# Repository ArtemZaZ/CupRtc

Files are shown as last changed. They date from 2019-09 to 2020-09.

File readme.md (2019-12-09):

# Проект для кубка РТК
 Case_of_Cup содержит модель подарочного кубка в среде SolidWorks.
Пожелания, жалобы, конструктивная критика и тому подобное принимается в [вк](https://vk.com/al_kom_ru).

Фото9

Описание, как залить новую информацию для кубка описано в документе "Прошивка кубка.docx"

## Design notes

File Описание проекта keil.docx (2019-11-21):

# Структура проекта в keil

Данный проект задействует следующую периферию процессора stm32f103C8T6:

- DMA1 и TIM3 для работы с адресными светодиодами;
- TIM4 для реализации функций задержек;
- PA10,PA11,PA12,PA15,PB3,PB4 для работы с LCD дисплеем;
- SPI2 для работы с динамиком и внешней памятью EEPROM, PA9 и PB12 как CS соответственно;
- PA1 для тактовой кнопки;
- UART2 – для общения с ПК.

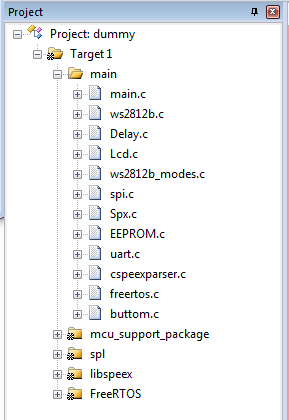
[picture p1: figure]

Данный проект задействует пакет библиотек SPL, LibSpeex и FreeRTOS. Важно замtтить, что большая часть функций переписана для успешной работы с операционной системой FreeRTOS. Также реализованы следующие библиотеки:

- ws2812b – работа с адресными светодиодами;
- Delay – функции задержек за счет таймера;
- Lcd – работа с lcd-дисплеем;
- ws2812b-modes – различные режимы работы светодиодов;
- spi – настройка интерфейса и таймера для работы динамика;
- Spx – инициализации библиотек libspeex и функций по запуску аудиофайла;
- EEPROM – для работы с внешней энергонезависимой памятью;
- uart – для записи данных с ПК на плату;
- cspeexparcer – для расшифровки пакета данных полученных по uart-у;
- freertos – настройка работы диспетчера задач и функций для него;
- buttom – функции для работы с тактовой кнопкой.

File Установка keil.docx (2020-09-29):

Итак, для прошивки кубка нам понадобиться µVision IDE – Keil. Качнуть можно его с многих ресурсов, труда не составит. Но есть прякол. В кейле который вы скачаете скорее всего будет мало место в линковщике (сколько не помню, но прошивка не соберется точно). Для решения проблемы надо стать немножко пиратом.

Далее говорить нечего, просто оставляю две ссылки на видосики, которые помогут спокойно решить проблему (ссылки на необходимые файлы можно найти в описании к видео).

(http://www2.keil.com/mdk5/uvision/)https://www.youtube.com/watch?v=bSmml5kYX14

https://www.youtube.com/watch?v=xSqIlKJOs6A

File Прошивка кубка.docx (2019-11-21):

# Прошивка кубка

## Подготовка файлов для отправки в кубок

Перед тем как начать заливать информацию в кубок по uart-у, необходимо убедиться, что на компьютере установлен Python3. Версия питона ниже не подойдет. Далее качаем архив с проектом с GitHub, вот ссыль

https://github.com/RTC-SCTB/CupRtc

Если качали из мастер-ветки, то в корне есть две директории: keil и Python. Нас интересует второе. В директории Python нас могут заинтересовать два файла: audio.wav и conf.json.

conf.json

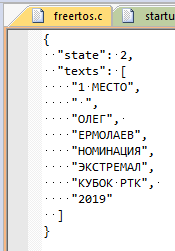
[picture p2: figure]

Открываем. Я открыл его в своем случае в keil-е. Советую открывать в каком-нибудь редакторе кода, т.к. можно будет указать кодировку файла, а она должна быть utf-8 (в кейле параметр encode in utf-8 without signature). В этом файле мы прописываем 8 текстов для дисплея и указываем место. Параметр state в данной конфигурации не учувствует, его можно не менять. Тексты записывать нужно из расчета на то, что в строку дисплея поместится 16 символов, могут быть написаны как в кириллице, так и в латинице. Тексты выводятся попарно, в первой и второй строке соответственно (1 и 2, 3 и 4 и т.д.). Заполняем примерно, как показано на скрине.

audio.wav

Это наш файл аудио, которое будет транслироваться на динамик.

Для начала нужно установить speex-кодировщик. Откуда я качал, не помню, поэтому в корне проекта лежит архив SpeexACM_1.0.1.1.zip. Его открываем, и запускаем exe-шник. (Маленькая пометка – делалось все на винде, как на линуксе будет, не известно).

После этого нам нужен какой-нибудь аудио-редактор, я использую jetAudio, он бесплатный, вот ссыль http://www.jetaudio.com/download/. Устанавливаем. Открываем, и переходим в окно конвертации.

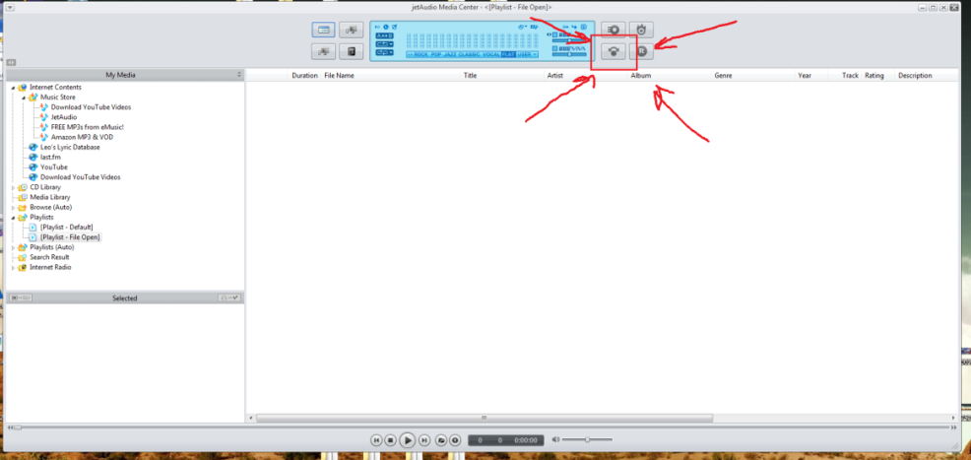
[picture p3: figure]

После этого добавляем новый файл в конвертер:

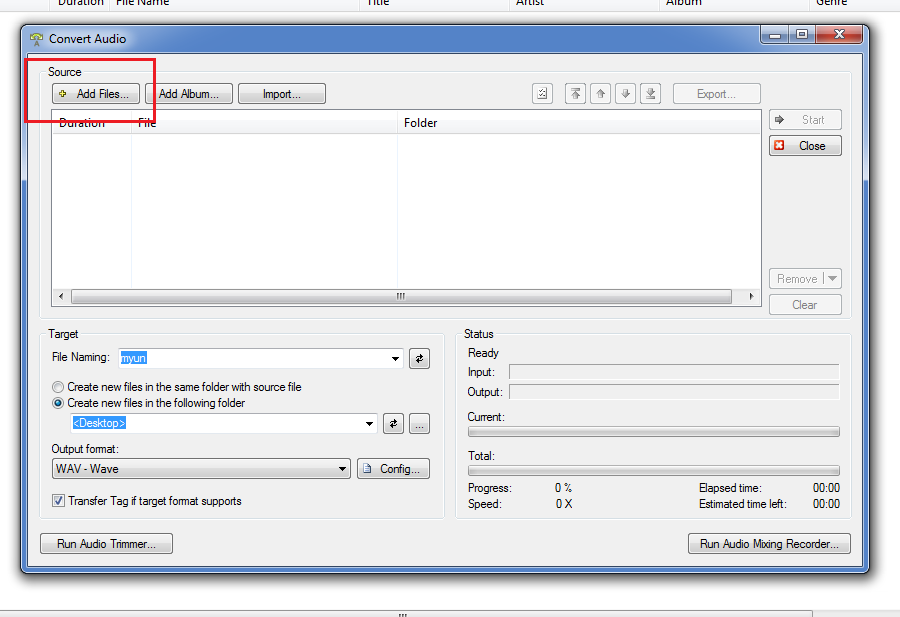
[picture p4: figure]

Далее даем название файлу “audio” (1), указываем куда сохранить (2), ставим формат конвертации WAV (3) и заходим в окно конфигурации формата (4).

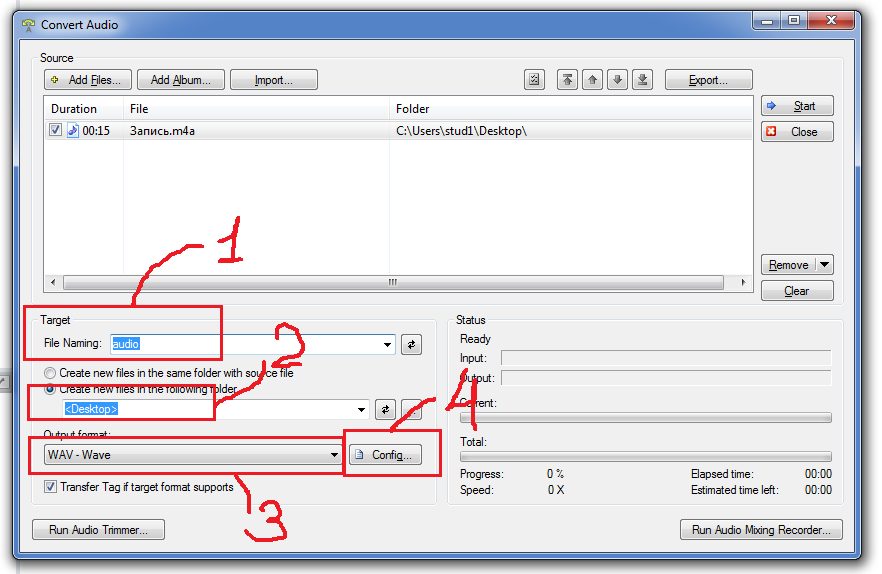
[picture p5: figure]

В окне конфигурации нажимаем select wav format, и выставляем следующие настройки: SPEEX, 8.0 kBit/s. 8.0kHz, Mono, Q4 0 КБ/с.

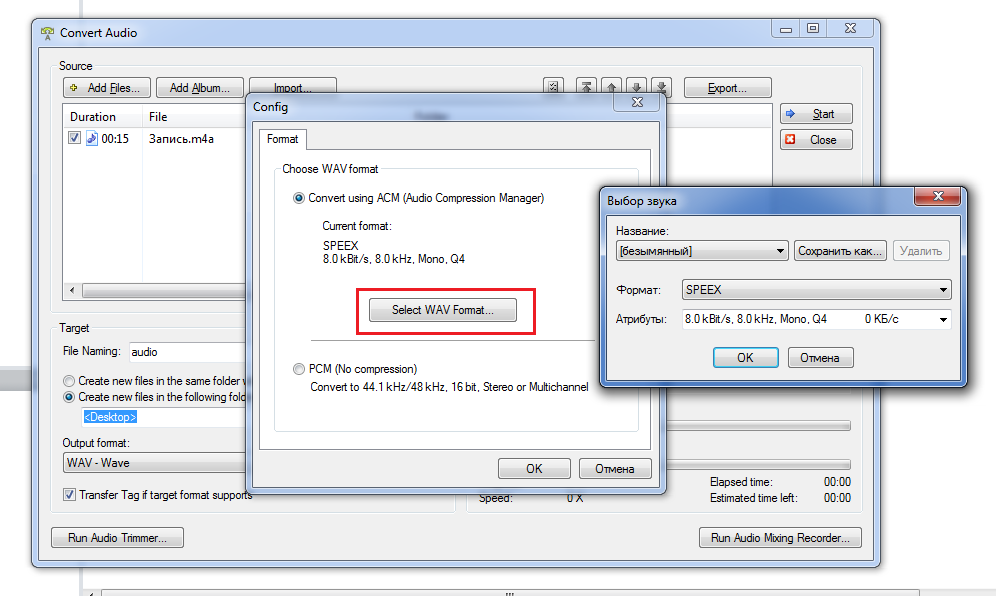
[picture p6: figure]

Далее жмем окей и окей и нажимаем Start. Все, файл готов. Закидываем его в папку Python нашего проекта.

## Отправка данных в кубок

Подсоединяем кубок к компьютеру через преобразователь usb-uart. Выглядит это как то так:

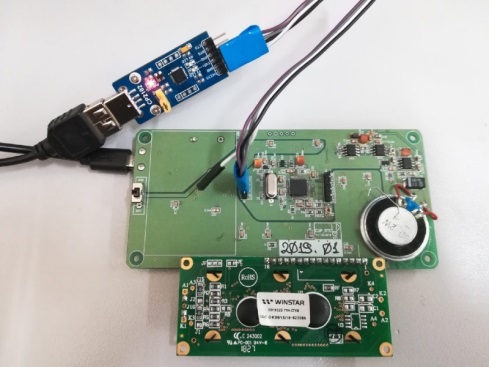
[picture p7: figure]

Открываем консоль. В консоли переходим в директорию проекта и папку Python. Например командой: cd Desktop\CupRtc\Python. Далее прописываем следующую команду, запускающую наш файл loader.py:

C:\Users\stud1\AppData\Local\Programs\Python\Python36-32\python.exe loader.py

Первая часть команды это путь до файла python.exe.

Есть следующие параметры запуска:

- --help – даст справку о параметрах;
- -с – имя файла json c текстами. По умолчанию conf.json. Можно править просто этот файл.
- -s – имя файла speex. По умолчанию audio.wav.
- -p – com-порт, к которому подключен преобразователь. По умолчанию COM3.
- -b – скорость передачи, по умолчанию она 19200, менять ее не надо, т.к. в кубке она тоже 19200.

Исходя из выше сказанного команда может преобразиться в:

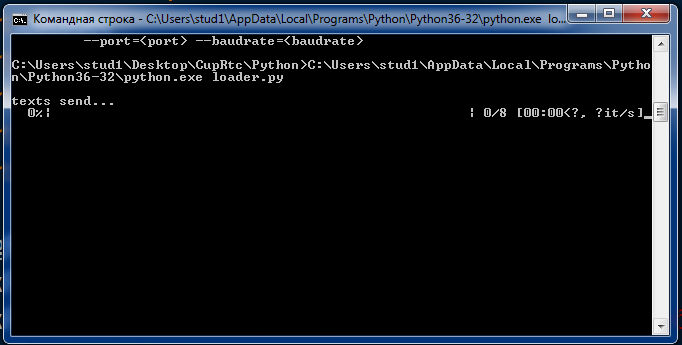
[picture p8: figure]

C:\Users\stud1\AppData\Local\Programs\Python\Python36-32\python.exe loader.py –с tezts.json –s voice.wav –p COM5

После того, как ввели команду, и появилось ожидание отправки текста, зажимаем кнопку на плате кубка и включаем его. Как пошла прошивка, кнопку можно отпустить.

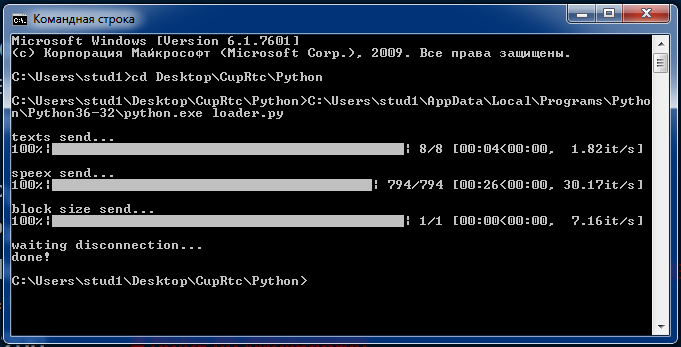
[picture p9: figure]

Окончание прошивки выглядит следующим образом. После отсоединяем преобразователь и перезапускаем кубок, проверяем, что все работает.

Все, кубки прошиты, спасибо за внимание ;-)

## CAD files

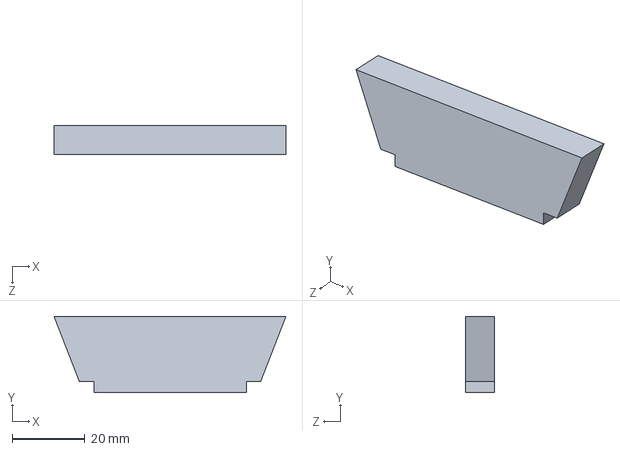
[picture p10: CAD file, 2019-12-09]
Case_of_Cup/Башня.SLDPRT
64.0 x 21.0 x 8.00 mm

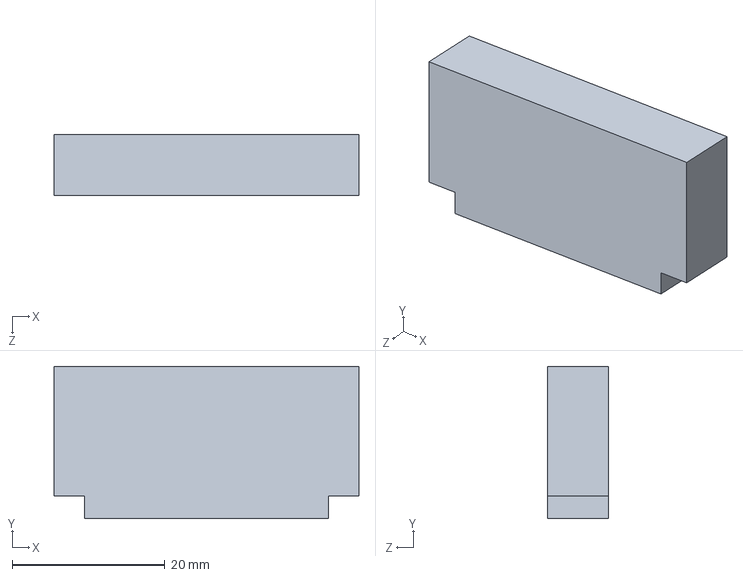
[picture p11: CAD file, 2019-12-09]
Case_of_Cup/Робот.SLDPRT
40.0 x 20.0 x 8.00 mm

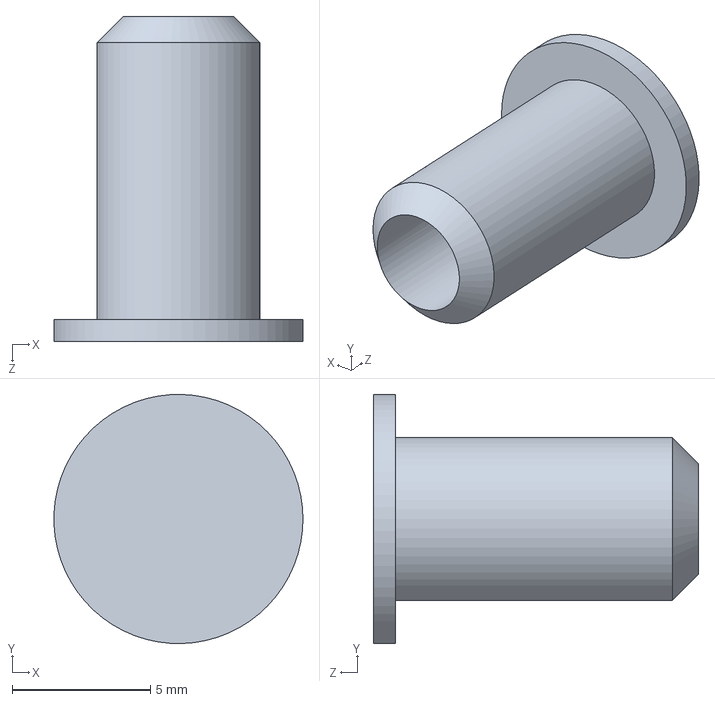
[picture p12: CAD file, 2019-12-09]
Case_of_Cup/Заклепка-гайка.SLDPRT
8.99 x 9.00 x 11.8 mm

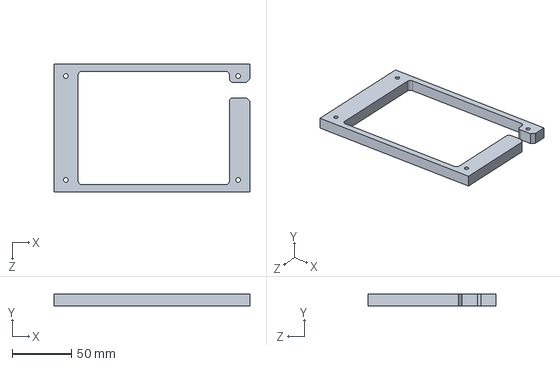
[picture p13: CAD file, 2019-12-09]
Case_of_Cup/Третья_ступень.SLDPRT
166.0 x 10.0 x 108.0 mm

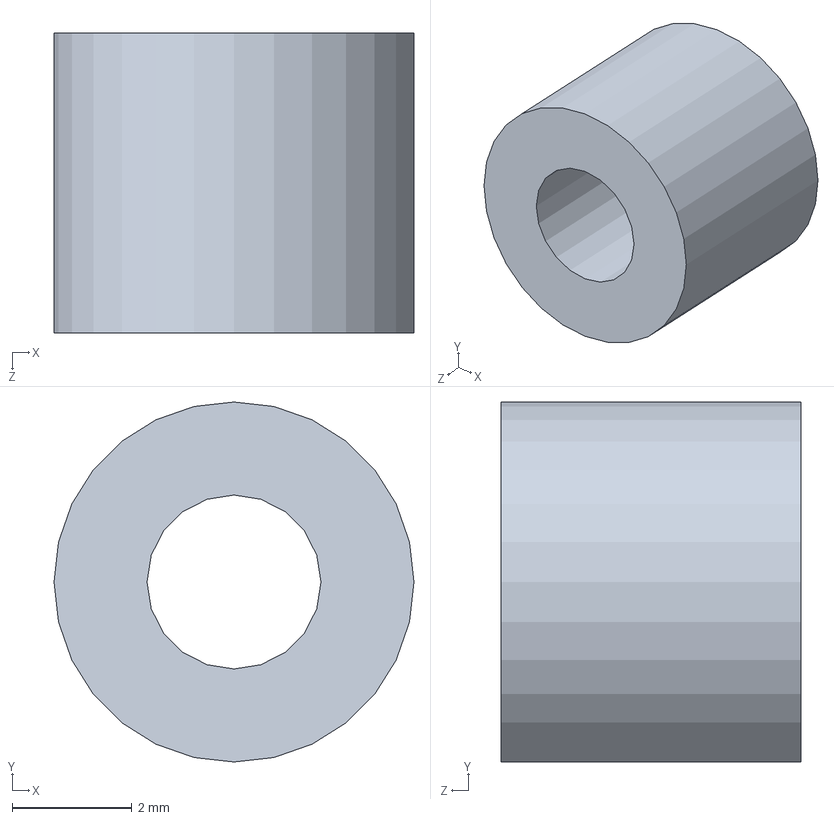
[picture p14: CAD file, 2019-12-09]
Case_of_Cup/Стойка_для_крепления_платы.SLDPRT
6.00 x 6.00 x 5.00 mm

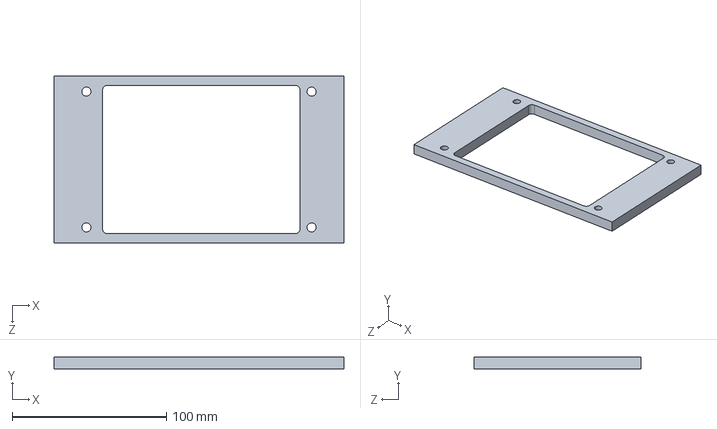
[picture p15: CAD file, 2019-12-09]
Case_of_Cup/Вторая_ступень.SLDPRT
188.0 x 8.00 x 108.0 mm

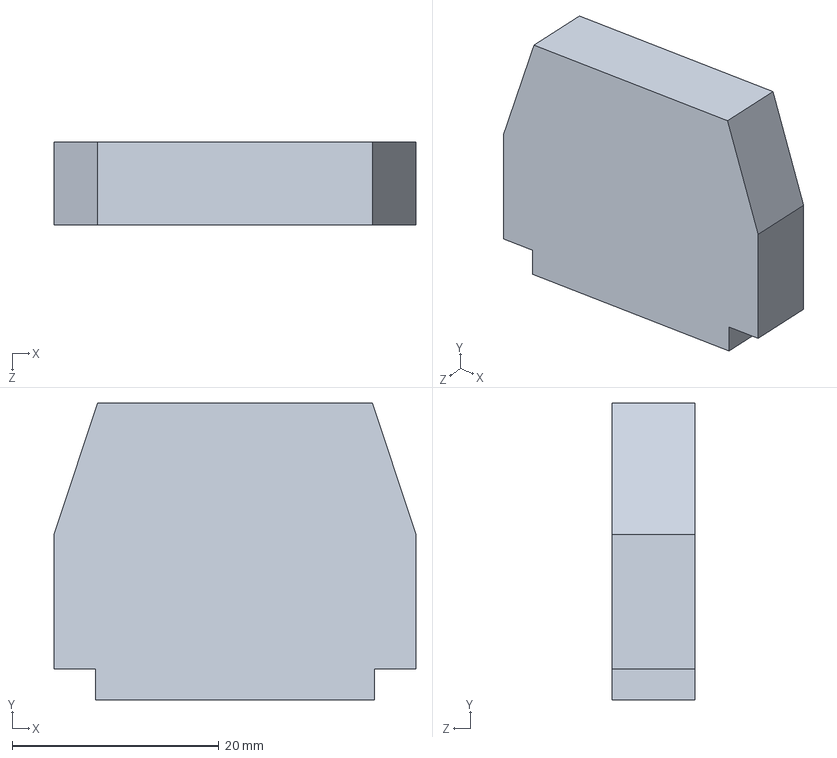
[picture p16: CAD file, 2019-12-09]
Case_of_Cup/Парень.SLDPRT
35.0 x 28.7 x 8.00 mm

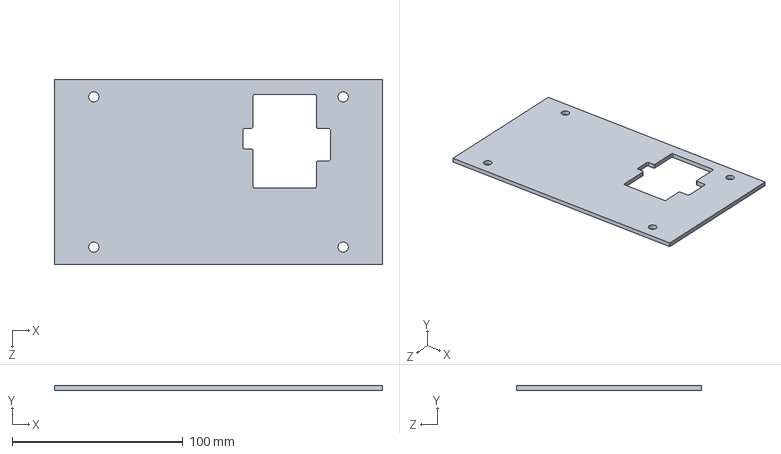
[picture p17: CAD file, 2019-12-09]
Case_of_Cup/Первая_ступень.SLDPRT
192.0 x 3.00 x 108.0 mm

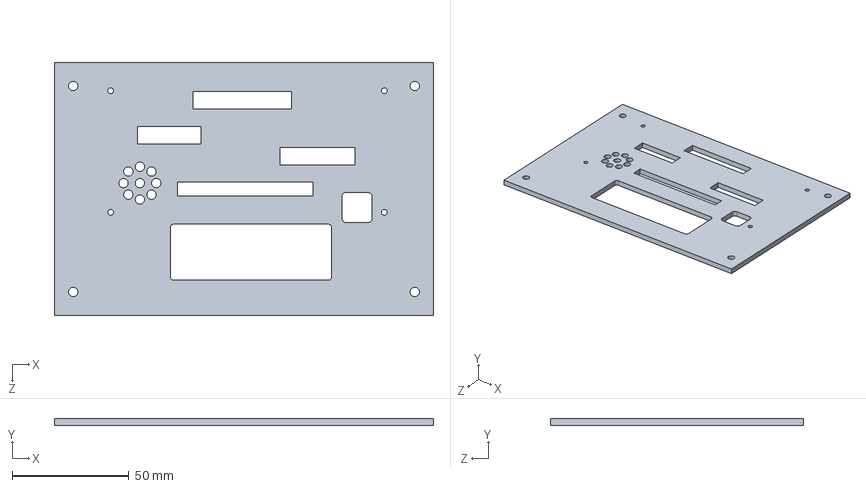
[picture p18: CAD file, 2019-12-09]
Case_of_Cup/Четвертая_ступень.SLDPRT
162.0 x 3.00 x 108.0 mm

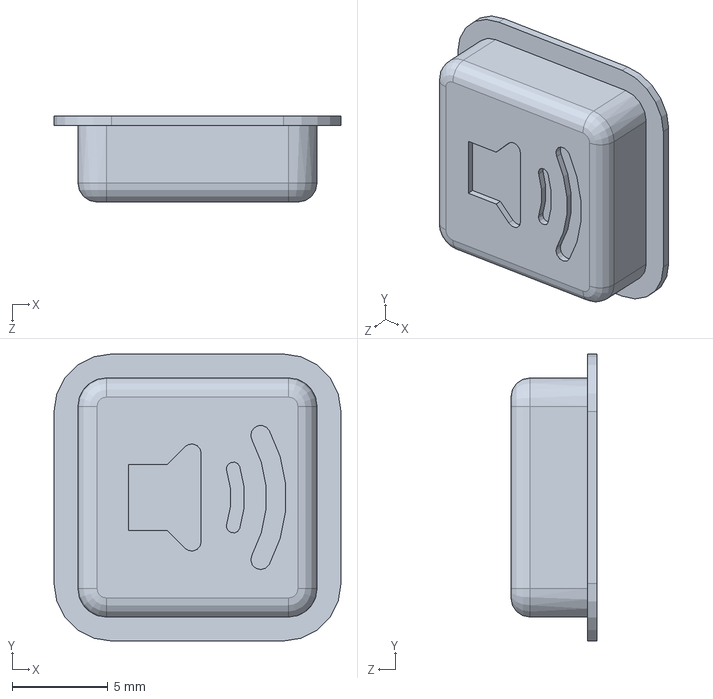
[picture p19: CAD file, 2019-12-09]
Case_of_Cup/Кнопка.SLDPRT
15.0 x 15.0 x 4.50 mm

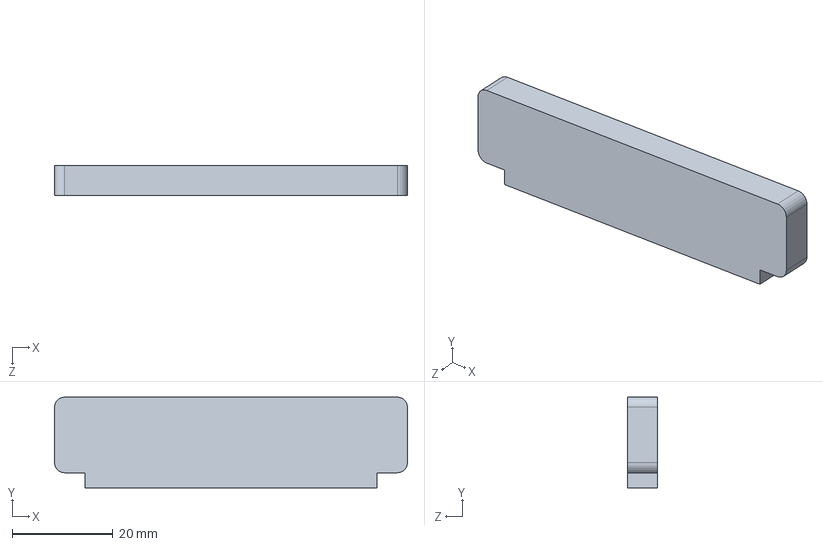
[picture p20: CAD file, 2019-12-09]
Case_of_Cup/Место_номинация.SLDPRT
70.0 x 18.0 x 6.00 mm

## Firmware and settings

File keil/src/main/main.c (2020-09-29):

#include "mcu_support_package/inc/stm32f10x.h"

#include <stdint.h>
#include <stdlib.h>
#include <stdio.h>

#include "Prj_config.h"

extern uint8_t r2d2[]; 
extern uint16_t r2d2_size;

int main(){
	Delay_Init();
	Serial_Init();
	EEPROM_SPI_Init();
	InitButtom();
	
	Wait_Data_Reception();
	
	ws2812b_init();
	Speex_Init();
	LCD_Init();
	delay_ms(10);
	play_message(r2d2, r2d2_size / 20);
	
	freertos_init();
	osKernelStart();
	
	while(1){
	}
}


// В Project->Options->Linker, Scatter File выбран файл stack_protection.sct
// он обеспечивает падение в HardFault при переполнении стека
// Из-за этого может выдаваться ложное предупреждение "AppData\Local\Temp\p2830-2(34): warning:  #1-D: last line of file ends without a newline"
#ifdef USE_FULL_ASSERT
// эта функция вызывается, если assert_param обнаружил ошибку
void assert_failed(uint8_t * file, uint32_t line)
{ 
    /* User can add his own implementation to report the file name and line number,
     ex: printf("Wrong parameters value: file %s on line %d\r\n", file, line) */
     
    (void)file;
    (void)line;

    __disable_irq();
    while(1)
    {
        // это ассемблерная инструкция "отладчик, стой тут"
        // если вы попали сюда, значит вы ошиблись в параметрах вызова функции из SPL. 
        // Смотрите в call stack, чтобы найти ее
        __BKPT(0xAB);
    }
}
#endif

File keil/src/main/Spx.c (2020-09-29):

#include "Spx.h"

volatile int16_t OUT_Buffer[2][FRAME_SIZE];
volatile int16_t *outBuffer;

volatile uint8_t Start_Decoding = 0;
SpeexBits bits;
void *enc_state, *dec_state;
int quality = 4, complexity=1, vbr=0, enh=1;

/*
*Инициализация пакета speex для воспроизведения звуков на динамике
*/
void Speex_Init(void)
{
	speex_bits_init(&bits);
	dec_state = speex_decoder_init(&speex_nb_mode);
	speex_decoder_ctl(dec_state, SPEEX_SET_ENH, &enh);
	outBuffer = OUT_Buffer[0];
	Speex_SPI_Init();
}

/*
*Инициализация переферии для speex-а
*/
void Speex_SPI_Init(void){
	//Настройка SPI
	RCC_APB1PeriphClockCmd(RCC_APB1Periph_SPI2, ENABLE);
	SPI_InitTypeDef SPI_Struct;
	SPI_Struct.SPI_Direction = SPI_Direction_2Lines_FullDuplex;
	SPI_Struct.SPI_Mode = SPI_Mode_Master;
	SPI_Struct.SPI_DataSize = SPI_DataSize_8b;
	SPI_Struct.SPI_CPOL = SPI_CPOL_Low;
	SPI_Struct.SPI_CPHA = SPI_CPHA_1Edge;
	SPI_Struct.SPI_NSS = SPI_NSS_Soft;
	SPI_Struct.SPI_BaudRatePrescaler = SPI_BaudRatePrescaler_4;
	SPI_Struct.SPI_FirstBit = SPI_FirstBit_MSB;
	SPI_Struct.SPI_CRCPolynomial = 10;
	SPI_Init(SPI2, &SPI_Struct);
	SPI_Cmd(SPI2, ENABLE);
	
	//Настройка Mosi
	SPEEX_MOSI_RCC_APBxPeriphClockCmd(SPEEX_MOSI_RCC_APBxPeriph_AFIO, ENABLE);
	SPEEX_MOSI_RCC_APBxPeriphClockCmd(SPEEX_MOSI_RCC_APBxPeriph_GPIOx, ENABLE);
	GPIO_InitTypeDef Mosi_Struct;
	Mosi_Struct.GPIO_Pin = SPEEX_MOSI_GPIO_Pin_x;
	Mosi_Struct.GPIO_Mode = SPEEX_MOSI_GPIO_Mode;
	Mosi_Struct.GPIO_Speed = SPEEX_MOSI_GPIO_Speed;
	GPIO_Init(SPEEX_MOSI_GPIOx, &Mosi_Struct);
	
	//Настройка Miso
	SPEEX_MISO_RCC_APBxPeriphClockCmd(SPEEX_MISO_RCC_APBxPeriph_AFIO, ENABLE);
	SPEEX_MISO_RCC_APBxPeriphClockCmd(SPEEX_MISO_RCC_APBxPeriph_GPIOx, ENABLE);
	GPIO_InitTypeDef Miso_Struct;
	Miso_Struct.GPIO_Pin = SPEEX_MISO_GPIO_Pin_x;
	Miso_Struct.GPIO_Mode = SPEEX_MISO_GPIO_Mode;
	Miso_Struct.GPIO_Speed = SPEEX_MISO_GPIO_Speed;
	GPIO_Init(SPEEX_MISO_GPIOx, &Miso_Struct);
	
	//Настройка CLK
	SPEEX_CLK_RCC_APBxPeriphClockCmd(SPEEX_CLK_RCC_APBxPeriph_AFIO, ENABLE);
	SPEEX_CLK_RCC_APBxPeriphClockCmd(SPEEX_CLK_RCC_APBxPeriph_GPIOx, ENABLE);
	GPIO_InitTypeDef Clk_Struct;
	Clk_Struct.GPIO_Pin = SPEEX_CLK_GPIO_Pin_x;
	Clk_Struct.GPIO_Mode = SPEEX_CLK_GPIO_Mode;
	Clk_Struct.GPIO_Speed = SPEEX_CLK_GPIO_Speed;
	GPIO_Init(SPEEX_CLK_GPIOx, &Clk_Struct);
	
	//Настройка CS
	SPEEX_CS_RCC_APBxPeriphClockCmd(SPEEX_CS_RCC_APBxPeriph_AFIO, ENABLE);
	SPEEX_CS_RCC_APBxPeriphClockCmd(SPEEX_CS_RCC_APBxPeriph_GPIOx, ENABLE);
	GPIO_InitTypeDef Cs_Struct;
	Cs_Struct.GPIO_Pin = SPEEX_CS_GPIO_Pin_x;
	Cs_Struct.GPIO_Mode = SPEEX_CS_GPIO_Mode;
	Cs_Struct.GPIO_Speed = SPEEX_CS_GPIO_Speed;
	GPIO_Init(SPEEX_CS_GPIOx, &Cs_Struct);
	GPIO_SetBits(SPEEX_CS_GPIOx, SPEEX_CS_GPIO_Pin_x);
	
	//Настройка TIM
	SPEEX_TIM_RCC_APBxPeriphClockCmd(SPEEX_TIM_RCC_APBxPeriph_TIMx, ENABLE);
	TIM_TimeBaseInitTypeDef Tim_Struct;
	Tim_Struct.TIM_Prescaler = SPEEX_TIM_TIM_Prescaler; //необходима частота 8кгц
	Tim_Struct.TIM_ClockDivision = SPEEX_TIM_TIM_ClockDivision;
	Tim_Struct.TIM_Period = SPEEX_TIM_TIM_Period;
	Tim_Struct.TIM_CounterMode = SPEEX_TIM_TIM_CounterMode;
	TIM_TimeBaseInit(SPEEX_TIM_TIMx, &Tim_Struct);
	NVIC_SetPriority(SPEEX_TIM_TIMx_IRQn, 0);
	
	TIM_ITConfig(SPEEX_TIM_TIMx, TIM_IT_Update, ENABLE);
}

/*
*Проигрование звука из памати процессора
*/
void play_message(unsigned char const *array, uint16_t frame_number)
{
	char input_bytes[ENCODED_FRAME_SIZE];
	volatile uint16_t NB_Frames=0;
	TIM_Cmd(SPEEX_TIM_TIMx, ENABLE);
	NVIC_EnableIRQ(SPEEX_TIM_TIMx_IRQn);
	int i;
	uint16_t sample_index = 0;
	for(i=0;i<ENCODED_FRAME_SIZE; i++)
	{
		input_bytes[i] = array[sample_index];
		sample_index++;
	}
	speex_bits_read_from(&bits, input_bytes, ENCODED_FRAME_SIZE);
	speex_decode_int(dec_state, &bits, (spx_int16_t*)OUT_Buffer[0]);
	NB_Frames++;
	for(i=0;i<ENCODED_FRAME_SIZE; i++)
	{
		input_bytes[i] = array[sample_index];
		sample_index++;
	} 
	speex_bits_read_from(&bits, input_bytes, ENCODED_FRAME_SIZE);
	speex_decode_int(dec_state, &bits, (spx_int16_t*)OUT_Buffer[1]);
	NB_Frames++;
	while(NB_Frames < frame_number)
	{
		if(Start_Decoding == 1)
		{
			for(i=0;i<ENCODED_FRAME_SIZE; i++)
			{
				input_bytes[i] = array[sample_index];
				sample_index++;
			}
			speex_bits_read_from(&bits, input_bytes, ENCODED_FRAME_SIZE);
			speex_decode_int(dec_state, &bits, (spx_int16_t*)OUT_Buffer[0]);
			
			Start_Decoding = 0;
			NB_Frames++;
		}
		if(Start_Decoding == 2)
		{
			for(i=0;i<ENCODED_FRAME_SIZE; i++)
			{
				input_bytes[i] = array[sample_index];
				sample_index++;
			}
			speex_bits_read_from(&bits, input_bytes, ENCODED_FRAME_SIZE);
			speex_decode_int(dec_state, &bits, (spx_int16_t*)OUT_Buffer[1]);
			
			Start_Decoding = 0;
			NB_Frames++;
		}
	}
	
	TIM_Cmd(SPEEX_TIM_TIMx, DISABLE);
	NVIC_DisableIRQ(SPEEX_TIM_TIMx_IRQn);
	sample_index = 0;
	NB_Frames = 0;
	outBuffer = OUT_Buffer[0];
}

/*
*Проигрование звука из внешней памяти eeprom
*Да, можно было сделать одной функцией, но мне было лень
*/
void play_message_from_eeprom(uint16_t address, uint16_t frame_number){
	volatile uint16_t NB_Frames=0;
	char input_bytes[ENCODED_FRAME_SIZE];
	EEPROM_Read_Buffer((uint8_t *)input_bytes, 20, address);
	address += 20;
	speex_bits_read_from(&bits, input_bytes, ENCODED_FRAME_SIZE);
	speex_decode_int(dec_state, &bits, (spx_int16_t*)OUT_Buffer[0]);
	
	EEPROM_Read_Buffer((uint8_t *)input_bytes, 20, address);
	address += 20;
	speex_bits_read_from(&bits, input_bytes, ENCODED_FRAME_SIZE);
	speex_decode_int(dec_state, &bits, (spx_int16_t*)OUT_Buffer[1]);
	NB_Frames+=2;
	
	TIM_Cmd(SPEEX_TIM_TIMx, ENABLE);
	NVIC_EnableIRQ(SPEEX_TIM_TIMx_IRQn);

	while(NB_Frames < frame_number)
	{
		if(Start_Decoding == 1)
		{
			EEPROM_Read_Buffer((uint8_t *)input_bytes, 20, address);
			address += 20;
			speex_bits_read_from(&bits, input_bytes, ENCODED_FRAME_SIZE);
			speex_decode_int(dec_state, &bits, (spx_int16_t*)OUT_Buffer[0]);
			Start_Decoding = 0;
			NB_Frames++;
		}
		if(Start_Decoding == 2)
		{
			EEPROM_Read_Buffer((uint8_t *)input_bytes, 20, address);
			address += 20;
			speex_bits_read_from(&bits, input_bytes, ENCODED_FRAME_SIZE);
			speex_decode_int(dec_state, &bits, (spx_int16_t*)OUT_Buffer[1]);
			Start_Decoding = 0;
			NB_Frames++;
		}
		taskYIELD();
	}
	taskYIELD();
	NVIC_DisableIRQ(SPEEX_TIM_TIMx_IRQn);
	TIM_Cmd(SPEEX_TIM_TIMx, DISABLE);
	NB_Frames = 0;
	outBuffer = OUT_Buffer[0];
	taskYIELD();
}
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

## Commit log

2018-01-26 Сделал ненужные методы статичными
2018-01-26 Revert "Сделал ненужные методы статичными"
    This reverts commit b1e4e668766c463d8754a2fbf2d7e3361899332c.
2018-01-26 Готовая, не тестированная версия
2018-01-26 Удалил лишнее
2018-01-26 Добавил графическое приложение на питоне
2018-02-12 Исправил жесткие косяки
2018-02-23 Немного оптимизировал код
2019-09-05 Почти написал новую версию прошиватора для подарочного кубка
2019-09-05 убрал ошибку слияния
2019-09-06 сделал из кода утилиту
2019-09-09 Начал писать парсер протокола на Си
2019-09-10 Дописал парсер протокола на си, необходимо тестирование
2019-09-11 отрефакторил под кейл + потестил и пофиксил пару ошибок
    в main.c подтягиваются сторониие зависимости для работы с UART, можно использовать другие
2019-09-11 Протестировал загрузчик, добавил модуль crc16 для совместимости с win, добавил тестовый проект для проверки cspeexparser
2019-09-11 убрал лишнее
2019-09-13 Добавил сообщение об окончании связи
2019-10-16 Поправил открытие файлов разными кодеками на разных системах
2019-10-16 Добавил progressbar
2019-11-12 Добавил кодировку кирилицы через кодек lcd + возможность совмещать кириллицу и латиницу
2019-11-15 слияние проектов
2019-11-15 старый проект на HAL
    [Stm32f103c8_cup Run.cfg, Stm32f103c8_cup_old Run (1).cfg, Stm32f103c8_cup_old Run.cfg]
2019-11-15 keil: считавание кол-ва блоков с епрома
2019-11-15 Убрал пакет state, добавил пакет количества блоков
2019-11-18 исправлен бак с кнопкой
2019-11-18 навожу красоту
2019-11-21 изменено и добавлено новое описание
2019-12-05 Корпус для подарочного кубка в среде SolidWorks 2017. Версия для финала Кубка РТК 2019.
    [Башня.SLDPRT, Вторая_ступень.SLDPRT, Заклепка-гайка.SLDPRT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]
2019-12-09 5ая страница, доп звуки, загрузка звука на дисплее
2020-09-29 Код претерпел значительно ревью
2020-09-29 Добавлен файлик с установкой кейла
2020-09-29 Файл с установкой кейла
